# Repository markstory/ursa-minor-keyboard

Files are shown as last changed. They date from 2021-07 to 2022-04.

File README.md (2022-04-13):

# Ursa Minor Keyboard

This repository contains design and schematic files for the usra-minor keyboard design.

## Handwired

This directory contains the design files used to create the initial prototype of the tryptris keyboard.
You can find a design/build guide on my blog:

* [Part 1](http://mark-story.com/posts/view/building-a-split-keyboard-part-1)
* [Part 2](http://mark-story.com/posts/view/building-a-split-keyboard-part-2)
* [Part 3](http://mark-story.com/posts/view/building-a-split-keyboard-part-3)

## v01

This directory contains the first drafts of the PCB based build. I've completed
design on two variants. Both have been printed and tested. A few defects were
found in the `v01/bling` board. These defects have been corrected. I've posted
a [longer article on the design and production](http://mark-story.com/posts/view/designing-my-first-keyboard-pcb).

### Notable Features

* **Single MCU** - Instead of dual microcontrollers, this design uses only
  a microcontroller and IO expander pairing. This lets more cost effective
  components be used and only requires a single flash operation when updating
  firmware.
* **Thumb Arc** The thumb cluster follows the thumb's natural arc, and all keys
  are reachable in 1u of space. Unlike many thumb arcs, this one requires no
  reaching under the palm.
* **No Frills, or Frills** The base model has a simple stripped down keyboard.
  It has no lights, no encoders, just 58 switches and wires. The bling model
  includes support for per-key RGB.

### v01/base

**🖨Printed, ✅Tested**

This is a basic board design. It has has no frills and a smaller parts list. The intention is that it used caseless with self-adhesive feet, or directly on a desk.

### v01/bling

**🖨Printed, ✅Tested**

This design builds on caseless foundatin of the `v01/base` and adds per-key RGB lighting via RGB matrix drivers over I2C. Like the base board it is intended to be used caseless.

### v01/bling-case

**🏗Work In Progress**

This board is a distinct design from `v01/bling` & `v01/base`. It is intended to be used with a switch plate and hollow body case.

### Firmware

Firmware for the `v01/base` and `v01/bling` can be found [in my QMK fork][https://github.com/markstory/qmk_firmare/tree/ursa-minor-v1].

## FAQ

**Why Ursa Minor?**

The keypad shape and thumb arc remind me of [Ursa Minor](https://en.wikipedia.org/wiki/Ursa_Minor).

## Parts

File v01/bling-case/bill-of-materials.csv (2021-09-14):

Id | Designator | Package | Quantity | Designation | Supplier | Part number | Price per | Total per board
3 | C16,C19,C18,C17,C15,C14,C6,C5,C4 | C_0805_2012Metric | 9 | 0.1uF | digikey | 08053C104KAT2A | 0.14 | 1.26
4 | U4,U3 | TQFP-48-1EP_7x7mm_P0.5mm_EP5x5mm | 2 | IS31FL3733-TQ | digikey | IS31FL3733B-TQLS4-TR | 4.94 | 9.88
5 | R14,R13 | R_0805_2012Metric | 2 | 20K | digikey | RMCF0805JT20K0 | 0.15 | 0.3
6 | R12,R11,R10,R9 | R_0805_2012Metric | 4 | 100K | digikey | RMCF0805JT100K | 0.15 | 0.6
7 | D1-54 | RGB_3528_Blue_Notch-MX | 54 | 6028 LED | aliexpress | /item/32834931333 | 0.122142857142857 | 6.59571428571429
8 | C21,C20,C13,C12,C11,C10,C9,C8 | C_0805_2012Metric | 8 | 0.47uF | digikey | CL21B474KOFNNNE | 0.14 | 1.12
10 | R7,R6 | R_0805_2012Metric | 2 | 4.7k | digikey | ERJ-PB6B4701V | 0.48 | 0.96
11 | J3 | USB_C_GCT_USB4085 | 1 | I2C-R | mouser | USB4085-GF-A | 1.28 | 1.28
12 | J2 | USB_C_GCT_USB4085 | 1 | I2C-L | mouser | USB4085-GF-A | 1.28 | 1.28
73 | J1 | USB_C_GCT_USB4085 | 1 | USB_C_Receptacle_USB2.0 | mouser | USB4085-GF-A | 1.28 | 1.28
16 | F1 | Fuse_0805_2012Metric_Pad1.15x1.40mm_HandSolder | 1 | 500mA | digikey | 0ZCK0050FF2E | 0.25 | 0.25
17 | D1-54 | D_SOD-123 | 54 | 1N4148W | digikey | 1N4148W RHG | 0.23 | 12.42
20 | SW1 | SW_SPST_TL3342 | 1 | Reset | digikey | TL3342F160QG/TR | 0.96 | 0.96
74 | Y1 | Crystal_SMD_3225-4Pin_3.2x2.5mm | 1 | 16Mhz | digikey | ECS-160-8-33-RHN-TR | 0.81 | 0.81
75 | U2 | SOIC-28W_7.5x17.9mm_P1.27mm | 1 | MCP23017_SO | mouser | 579-MCP23017T-E/SO | 1.92 | 1.92
76 | U1 | TQFP-44_10x10mm_P0.8mm | 1 | ATmega32U4-AU | digikey | ATMEGA32U4RC-AU | 7.46 | 7.46
77 | R8,R1 | R_0805_2012Metric | 2 | 10k | digikey | RMCF0805JT10K0 | 0.15 | 0.3
78 | R5,R4 | R_0805_2012Metric | 2 | 22 | digikey | RMCF0805FT22R0 | 0.15 | 0.3
79 | R3,R2 | R_0805_2012Metric | 2 | 5.1K | digikey | RMCF0805FT5K10 | 0.15 | 0.3
80 | C7 | C_0805_2012Metric | 1 | 10uF | digikey | C0805C106K9PACTU | 0.2 | 0.2
81 | C3 | C_0805_2012Metric | 1 | 1uF | digikey | 08056D104KAT2A | 0.14 | 0.14
82 | C2,C1 | C_0805_2012Metric | 2 | 22pF | digikey | CL21A226MQQNNNE | 0.2 | 0.4
 |  |  |  |  |  |  |  | 50.0157142857143

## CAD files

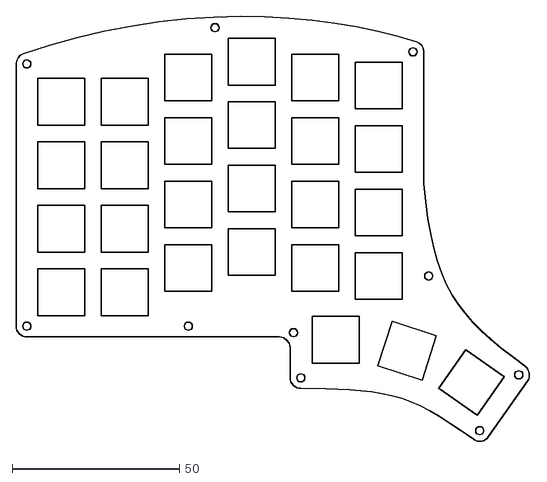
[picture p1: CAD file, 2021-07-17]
handwired/switchplate.dxf
154.1 x 127.3

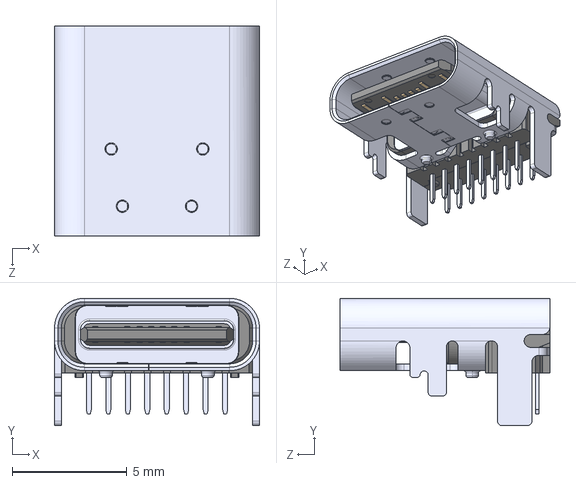
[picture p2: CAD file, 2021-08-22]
sym/3dmodels/USB4085-GF-A.step
8.95 x 5.56 x 9.17 mm

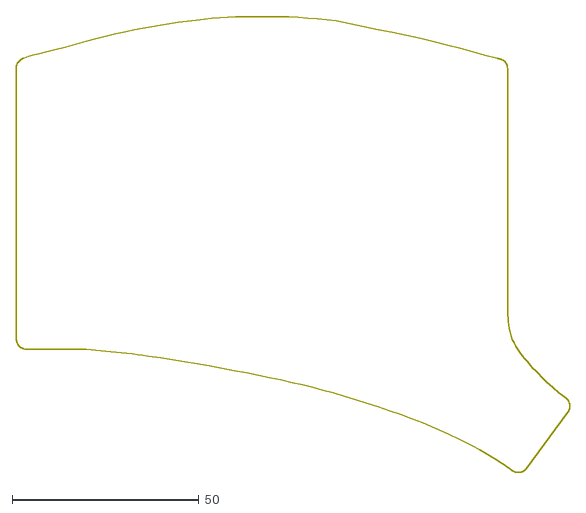
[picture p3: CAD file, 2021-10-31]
v01/drawing/left-board-outline.dxf
148.1 x 122.0

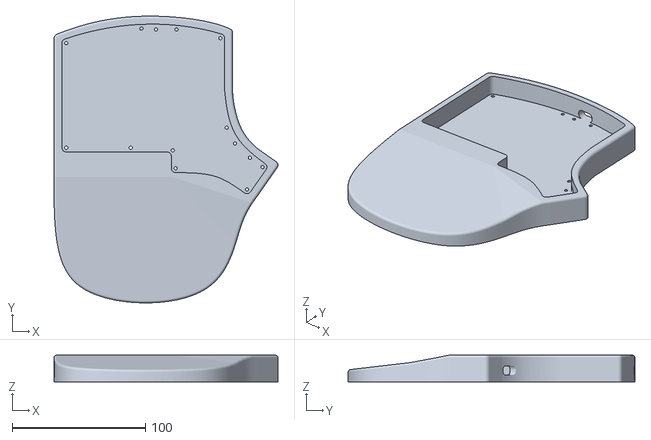
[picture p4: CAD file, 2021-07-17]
handwired/case-palmrest.stl
168.0 x 215.1 x 20.0

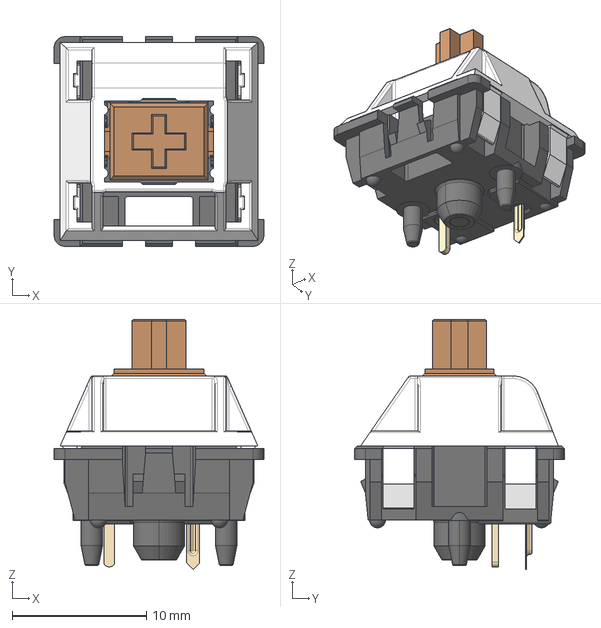
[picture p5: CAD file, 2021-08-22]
sym/3dmodels/MX-Alps-Choc-1U-NoLED.step
15.6 x 15.6 x 18.6 mm

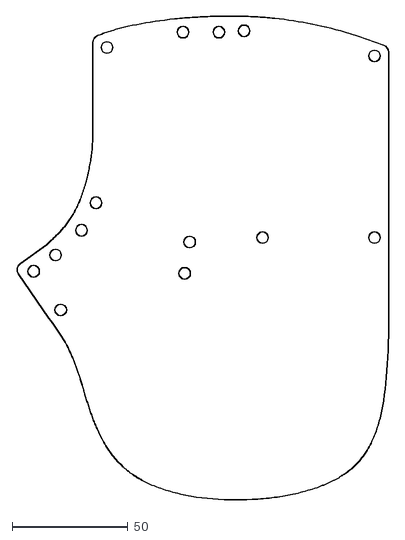
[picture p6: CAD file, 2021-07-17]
handwired/palmrest-mat.dxf
161.0 x 209.1

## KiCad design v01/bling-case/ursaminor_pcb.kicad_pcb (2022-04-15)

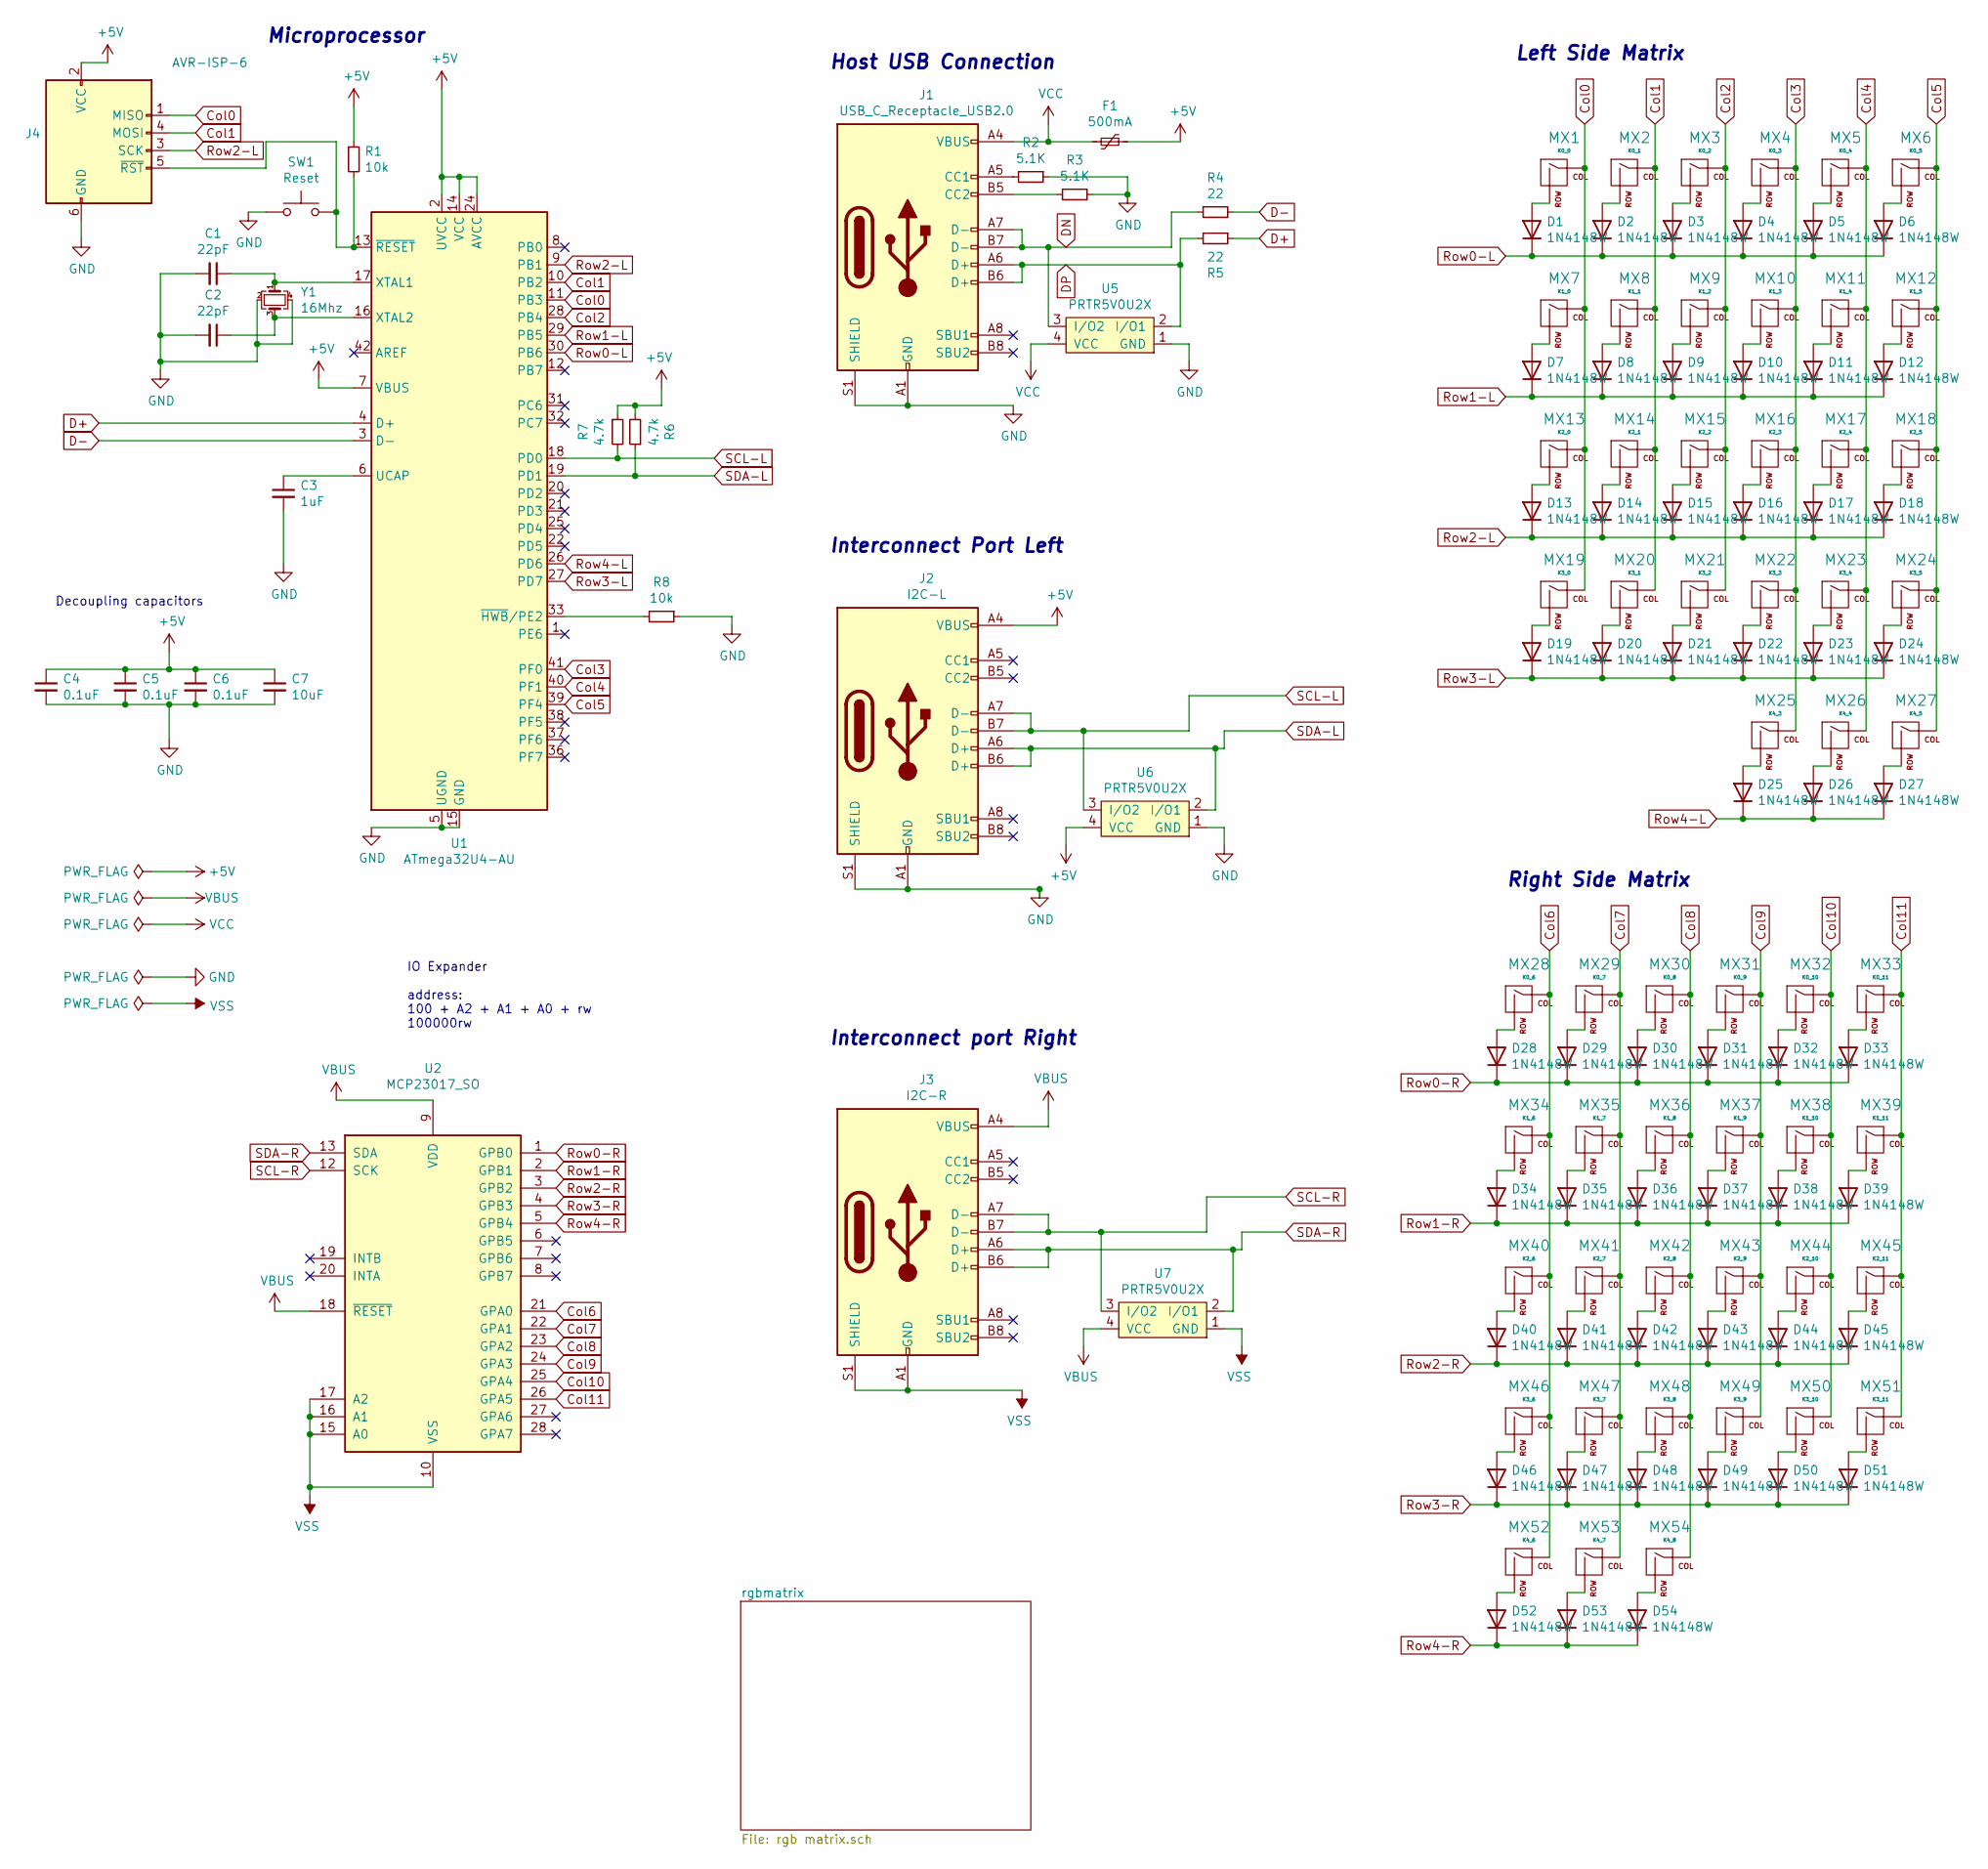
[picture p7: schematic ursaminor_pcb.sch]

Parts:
C1, C2: 22pF; C_0805_2012Metric
C3: 1uF; C_0805_2012Metric
C4, C5, C6: 0.1uF; C_0805_2012Metric
C7: 10uF; C_0805_2012Metric
D1, D2, D3, D4, D5, D6, D7, D8, D9, D10, D11, D12, D13, D14, D15, D16, D17, D18, D19, D20, D21, D22, D23, D24, D25, D26, D27, D28, D29, D30, D31, D32, D33, D34, D35, D36, D37, D38, D39, D40, D41, D42, D43, D44, D45, D46, D47, D48, D49, D50, D51, D52, D53, D54: 1N4148W; D_SOD-123
F1: 500mA; Fuse_1206_3216Metric_Pad1.42x1.75mm_HandSolder
J1: USB_C_Receptacle_USB2.0; USB_C_Receptacle_HRO_TYPE-C-31-M-12
J2: I2C-L; USB_C_Receptacle_HRO_TYPE-C-31-M-12
J3: I2C-R; USB_C_Receptacle_HRO_TYPE-C-31-M-12
J4: AVR-ISP-6; Reset_Pretty-Mask
MX1: K0_0; MX-Alps-Choc-1U-NoLED
MX2: K0_1; MX-Alps-Choc-1U-NoLED
MX3: K0_2; MX-Alps-Choc-1U-NoLED
MX4: K0_3; MX-Alps-Choc-1U-NoLED
MX5: K0_4; MX-Alps-Choc-1U-NoLED
MX6: K0_5; MX-Alps-Choc-1U-NoLED
MX7: K1_0; MX-Alps-Choc-1U-NoLED
MX8: K1_1; MX-Alps-Choc-1U-NoLED
MX9: K1_2; MX-Alps-Choc-1U-NoLED
MX10: K1_3; MX-Alps-Choc-1U-NoLED
MX11: K1_4; MX-Alps-Choc-1U-NoLED
MX12: K1_5; MX-Alps-Choc-1U-NoLED
MX13: K2_0; MX-Alps-Choc-1U-NoLED
MX14: K2_1; MX-Alps-Choc-1U-NoLED
MX15: K2_2; MX-Alps-Choc-1U-NoLED
MX16: K2_3; MX-Alps-Choc-1U-NoLED
MX17: K2_4; MX-Alps-Choc-1U-NoLED
MX18: K2_5; MX-Alps-Choc-1U-NoLED
MX19: K3_0; MX-Alps-Choc-1U-NoLED
MX20: K3_1; MX-Alps-Choc-1U-NoLED
MX21: K3_2; MX-Alps-Choc-1U-NoLED
MX22: K3_3; MX-Alps-Choc-1U-NoLED
MX23: K3_4; MX-Alps-Choc-1U-NoLED
MX24: K3_5; MX-Alps-Choc-1U-NoLED
MX25: K4_3; MX-Alps-Choc-1U-NoLED
MX26: K4_4; MX-Alps-Choc-1U-NoLED
MX27: K4_5; MX-Alps-Choc-1U-NoLED
MX28: K0_6; MX-Alps-Choc-1U-NoLED
MX29: K0_7; MX-Alps-Choc-1U-NoLED
MX30: K0_8; MX-Alps-Choc-1U-NoLED
MX31: K0_9; MX-Alps-Choc-1U-NoLED
MX32: K0_10; MX-Alps-Choc-1U-NoLED
MX33: K0_11; MX-Alps-Choc-1U-NoLED
MX34: K1_6; MX-Alps-Choc-1U-NoLED
MX35: K1_7; MX-Alps-Choc-1U-NoLED
MX36: K1_8; MX-Alps-Choc-1U-NoLED
MX37: K1_9; MX-Alps-Choc-1U-NoLED
MX38: K1_10; MX-Alps-Choc-1U-NoLED
MX39: K1_11; MX-Alps-Choc-1U-NoLED
MX40: K2_6; MX-Alps-Choc-1U-NoLED
MX41: K2_7; MX-Alps-Choc-1U-NoLED
MX42: K2_8; MX-Alps-Choc-1U-NoLED
MX43: K2_9; MX-Alps-Choc-1U-NoLED
MX44: K2_10; MX-Alps-Choc-1U-NoLED
MX45: K2_11; MX-Alps-Choc-1U-NoLED
MX46: K3_6; MX-Alps-Choc-1U-NoLED
MX47: K3_7; MX-Alps-Choc-1U-NoLED
MX48: K3_8; MX-Alps-Choc-1U-NoLED
MX49: K3_9; MX-Alps-Choc-1U-NoLED
MX50: K3_10; MX-Alps-Choc-1U-NoLED
MX51: K3_11; MX-Alps-Choc-1U-NoLED
MX52: K4_6; MX-Alps-Choc-1U-NoLED
MX53: K4_7; MX-Alps-Choc-1U-NoLED
MX54: K4_8; MX-Alps-Choc-1U-NoLED
R1, R8: 10k; R_0805_2012Metric
R2, R3: 5.1K; R_0805_2012Metric
R4, R5: 22; R_0805_2012Metric
R6, R7: 4.7k; R_0805_2012Metric
SW1: Reset; SW_SPST_TL3342
U1: ATmega32U4-AU; TQFP-44_10x10mm_P0.8mm
U2: MCP23017_SO; SOIC-28W_7.5x17.9mm_P1.27mm
U5, U6, U7: PRTR5V0U2X; SOT-143B
Y1: 16Mhz; Crystal_SMD_3225-4Pin_3.2x2.5mm

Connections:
+5V: C4.1, C5.1, C6.1, C7.1, F1.1, J2.A4 (VBUS), J2.A9 (VBUS), J2.B4 (VBUS), J2.B9 (VBUS), J4.2 (VCC), R1.1, R6.2, R7.1, U1.2 (UVCC), U1.7 (VBUS), U1.14 (VCC), U1.24 (AVCC), U1.34 (VCC), U1.44 (AVCC), U6.4 (VCC); also elsewhere on the board
Col0: J4.1 (MISO), MX1.1 (COL), MX7.1 (COL), MX13.1 (COL), MX19.1 (COL), U1.11 (PB3)
Col1: J4.4 (MOSI), MX2.1 (COL), MX8.1 (COL), MX14.1 (COL), MX20.1 (COL), U1.10 (PB2)
Col2: MX3.1 (COL), MX9.1 (COL), MX15.1 (COL), MX21.1 (COL), U1.28 (PB4)
Col3: MX4.1 (COL), MX10.1 (COL), MX16.1 (COL), MX22.1 (COL), MX25.1 (COL), U1.41 (PF0)
Col4: MX5.1 (COL), MX11.1 (COL), MX17.1 (COL), MX23.1 (COL), MX26.1 (COL), U1.40 (PF1)
Col5: MX6.1 (COL), MX12.1 (COL), MX18.1 (COL), MX24.1 (COL), MX27.1 (COL), U1.39 (PF4)
Col6: MX28.1 (COL), MX34.1 (COL), MX40.1 (COL), MX46.1 (COL), MX52.1 (COL), U2.21 (GPA0)
Col7: MX29.1 (COL), MX35.1 (COL), MX41.1 (COL), MX47.1 (COL), MX53.1 (COL), U2.22 (GPA1)
Col8: MX30.1 (COL), MX36.1 (COL), MX42.1 (COL), MX48.1 (COL), MX54.1 (COL), U2.23 (GPA2)
Col9: MX31.1 (COL), MX37.1 (COL), MX43.1 (COL), MX49.1 (COL), U2.24 (GPA3)
Col10: MX32.1 (COL), MX38.1 (COL), MX44.1 (COL), MX50.1 (COL), U2.25 (GPA4)
Col11: MX33.1 (COL), MX39.1 (COL), MX45.1 (COL), MX51.1 (COL), U2.26 (GPA5)
D+: R5.1, U1.4 (D+)
D-: R4.2, U1.3 (D-)
DN: J1.A7 (D-), J1.B7 (D-), R4.1, U5.3 (I/O2)
DP: J1.A6 (D+), J1.B6 (D+), R5.2, U5.2 (I/O1)
GND: C1.2, C2.2, C3.2, C4.2, C5.2, C6.2, C7.2, J1.A1 (GND), J1.A12 (GND), J1.B1 (GND), J1.B12 (GND), J1.S1 (SHIELD), J2.A1 (GND), J2.A12 (GND), J2.B1 (GND), J2.B12 (GND), J2.S1 (SHIELD), J4.6 (GND), R2.1, R3.2, R8.1, SW1.1, U1.5 (UGND), U1.15 (GND), U1.23 (GND), U1.35 (GND), U1.43 (GND), U5.1 (GND), U6.1 (GND), Y1.2, Y1.4; also elsewhere on the board
unnamed: C1.1, U1.17 (XTAL1), Y1.1
unnamed: C2.1, U1.16 (XTAL2), Y1.3
unnamed: C3.1, U1.6 (UCAP)
unnamed: D1.2 (A), MX1.2 (ROW)
unnamed: D2.2 (A), MX2.2 (ROW)
unnamed: D3.2 (A), MX3.2 (ROW)
unnamed: D4.2 (A), MX4.2 (ROW)
unnamed: D5.2 (A), MX5.2 (ROW)
unnamed: D6.2 (A), MX6.2 (ROW)
unnamed: D7.2 (A), MX7.2 (ROW)
unnamed: D8.2 (A), MX8.2 (ROW)
unnamed: D9.2 (A), MX9.2 (ROW)
unnamed: D10.2 (A), MX10.2 (ROW)
unnamed: D11.2 (A), MX11.2 (ROW)
unnamed: D12.2 (A), MX12.2 (ROW)
unnamed: D13.2 (A), MX13.2 (ROW)
unnamed: D14.2 (A), MX14.2 (ROW)
unnamed: D15.2 (A), MX15.2 (ROW)
unnamed: D16.2 (A), MX16.2 (ROW)
unnamed: D17.2 (A), MX17.2 (ROW)
unnamed: D18.2 (A), MX18.2 (ROW)
unnamed: D19.2 (A), MX19.2 (ROW)
unnamed: D20.2 (A), MX20.2 (ROW)
unnamed: D21.2 (A), MX21.2 (ROW)
unnamed: D22.2 (A), MX22.2 (ROW)
unnamed: D23.2 (A), MX23.2 (ROW)
unnamed: D24.2 (A), MX24.2 (ROW)
unnamed: D25.2 (A), MX25.2 (ROW)
unnamed: D26.2 (A), MX26.2 (ROW)
unnamed: D27.2 (A), MX27.2 (ROW)
unnamed: D28.2 (A), MX28.2 (ROW)
unnamed: D29.2 (A), MX29.2 (ROW)
unnamed: D30.2 (A), MX30.2 (ROW)
unnamed: D31.2 (A), MX31.2 (ROW)
unnamed: D32.2 (A), MX32.2 (ROW)
unnamed: D33.2 (A), MX33.2 (ROW)
unnamed: D34.2 (A), MX34.2 (ROW)
unnamed: D35.2 (A), MX35.2 (ROW)
unnamed: D36.2 (A), MX36.2 (ROW)
unnamed: D37.2 (A), MX37.2 (ROW)
unnamed: D38.2 (A), MX38.2 (ROW)
unnamed: D39.2 (A), MX39.2 (ROW)
unnamed: D40.2 (A), MX40.2 (ROW)
unnamed: D41.2 (A), MX41.2 (ROW)
unnamed: D42.2 (A), MX42.2 (ROW)
unnamed: D43.2 (A), MX43.2 (ROW)
unnamed: D44.2 (A), MX44.2 (ROW)
unnamed: D45.2 (A), MX45.2 (ROW)
unnamed: D46.2 (A), MX46.2 (ROW)
unnamed: D47.2 (A), MX47.2 (ROW)
unnamed: D48.2 (A), MX48.2 (ROW)
unnamed: D49.2 (A), MX49.2 (ROW)
unnamed: D50.2 (A), MX50.2 (ROW)
unnamed: D51.2 (A), MX51.2 (ROW)
unnamed: D52.2 (A), MX52.2 (ROW)
unnamed: D53.2 (A), MX53.2 (ROW)
unnamed: D54.2 (A), MX54.2 (ROW)
unnamed: J1.A5 (CC1), R2.2
unnamed: J1.B5 (CC2), R3.1
unnamed: J4.5 (~RST), R1.2, SW1.2, U1.13 (~RESET)
unnamed: R8.2, U1.33 (~HWB~/PE2)
Row0-L: D1.1 (K), D2.1 (K), D3.1 (K), D4.1 (K), D5.1 (K), D6.1 (K), U1.30 (PB6)
Row0-R: D28.1 (K), D29.1 (K), D30.1 (K), D31.1 (K), D32.1 (K), D33.1 (K), U2.1 (GPB0)
Row1-L: D7.1 (K), D8.1 (K), D9.1 (K), D10.1 (K), D11.1 (K), D12.1 (K), U1.29 (PB5)
Row1-R: D34.1 (K), D35.1 (K), D36.1 (K), D37.1 (K), D38.1 (K), D39.1 (K), U2.2 (GPB1)
Row2-L: D13.1 (K), D14.1 (K), D15.1 (K), D16.1 (K), D17.1 (K), D18.1 (K), J4.3 (SCK), U1.9 (PB1)
Row2-R: D40.1 (K), D41.1 (K), D42.1 (K), D43.1 (K), D44.1 (K), D45.1 (K), U2.3 (GPB2)
Row3-L: D19.1 (K), D20.1 (K), D21.1 (K), D22.1 (K), D23.1 (K), D24.1 (K), U1.27 (PD7)
Row3-R: D46.1 (K), D47.1 (K), D48.1 (K), D49.1 (K), D50.1 (K), D51.1 (K), U2.4 (GPB3)
Row4-L: D25.1 (K), D26.1 (K), D27.1 (K), U1.26 (PD6)
Row4-R: D52.1 (K), D53.1 (K), D54.1 (K), U2.5 (GPB4)
SCL-L: J2.A7 (D-), J2.B7 (D-), R7.2, U1.18 (PD0), U6.3 (I/O2); also elsewhere on the board
SCL-R: J3.A7 (D-), J3.B7 (D-), U2.12 (SCK), U7.3 (I/O2); also elsewhere on the board
SDA-L: J2.A6 (D+), J2.B6 (D+), R6.1, U1.19 (PD1), U6.2 (I/O1); also elsewhere on the board
SDA-R: J3.A6 (D+), J3.B6 (D+), U2.13 (SDA), U7.2 (I/O1); also elsewhere on the board
VBUS: J3.A4 (VBUS), J3.A9 (VBUS), J3.B4 (VBUS), J3.B9 (VBUS), U2.9 (VDD), U2.18 (~RESET~), U7.4 (VCC); also elsewhere on the board
VCC: F1.2, J1.A4 (VBUS), J1.A9 (VBUS), J1.B4 (VBUS), J1.B9 (VBUS), U5.4 (VCC)
VSS: J3.A1 (GND), J3.A12 (GND), J3.B1 (GND), J3.B12 (GND), J3.S1 (SHIELD), U2.10 (VSS), U2.15 (A0), U2.16 (A1), U2.17 (A2), U7.1 (GND); also elsewhere on the board

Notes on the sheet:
Left Side Matrix
Host USB Connection
Microprocessor
Decoupling capacitors
IO Expander address: 100 + A2 + A1 + A0 + rw 100000rw
Right Side Matrix
Interconnect port Right
Interconnect Port Left

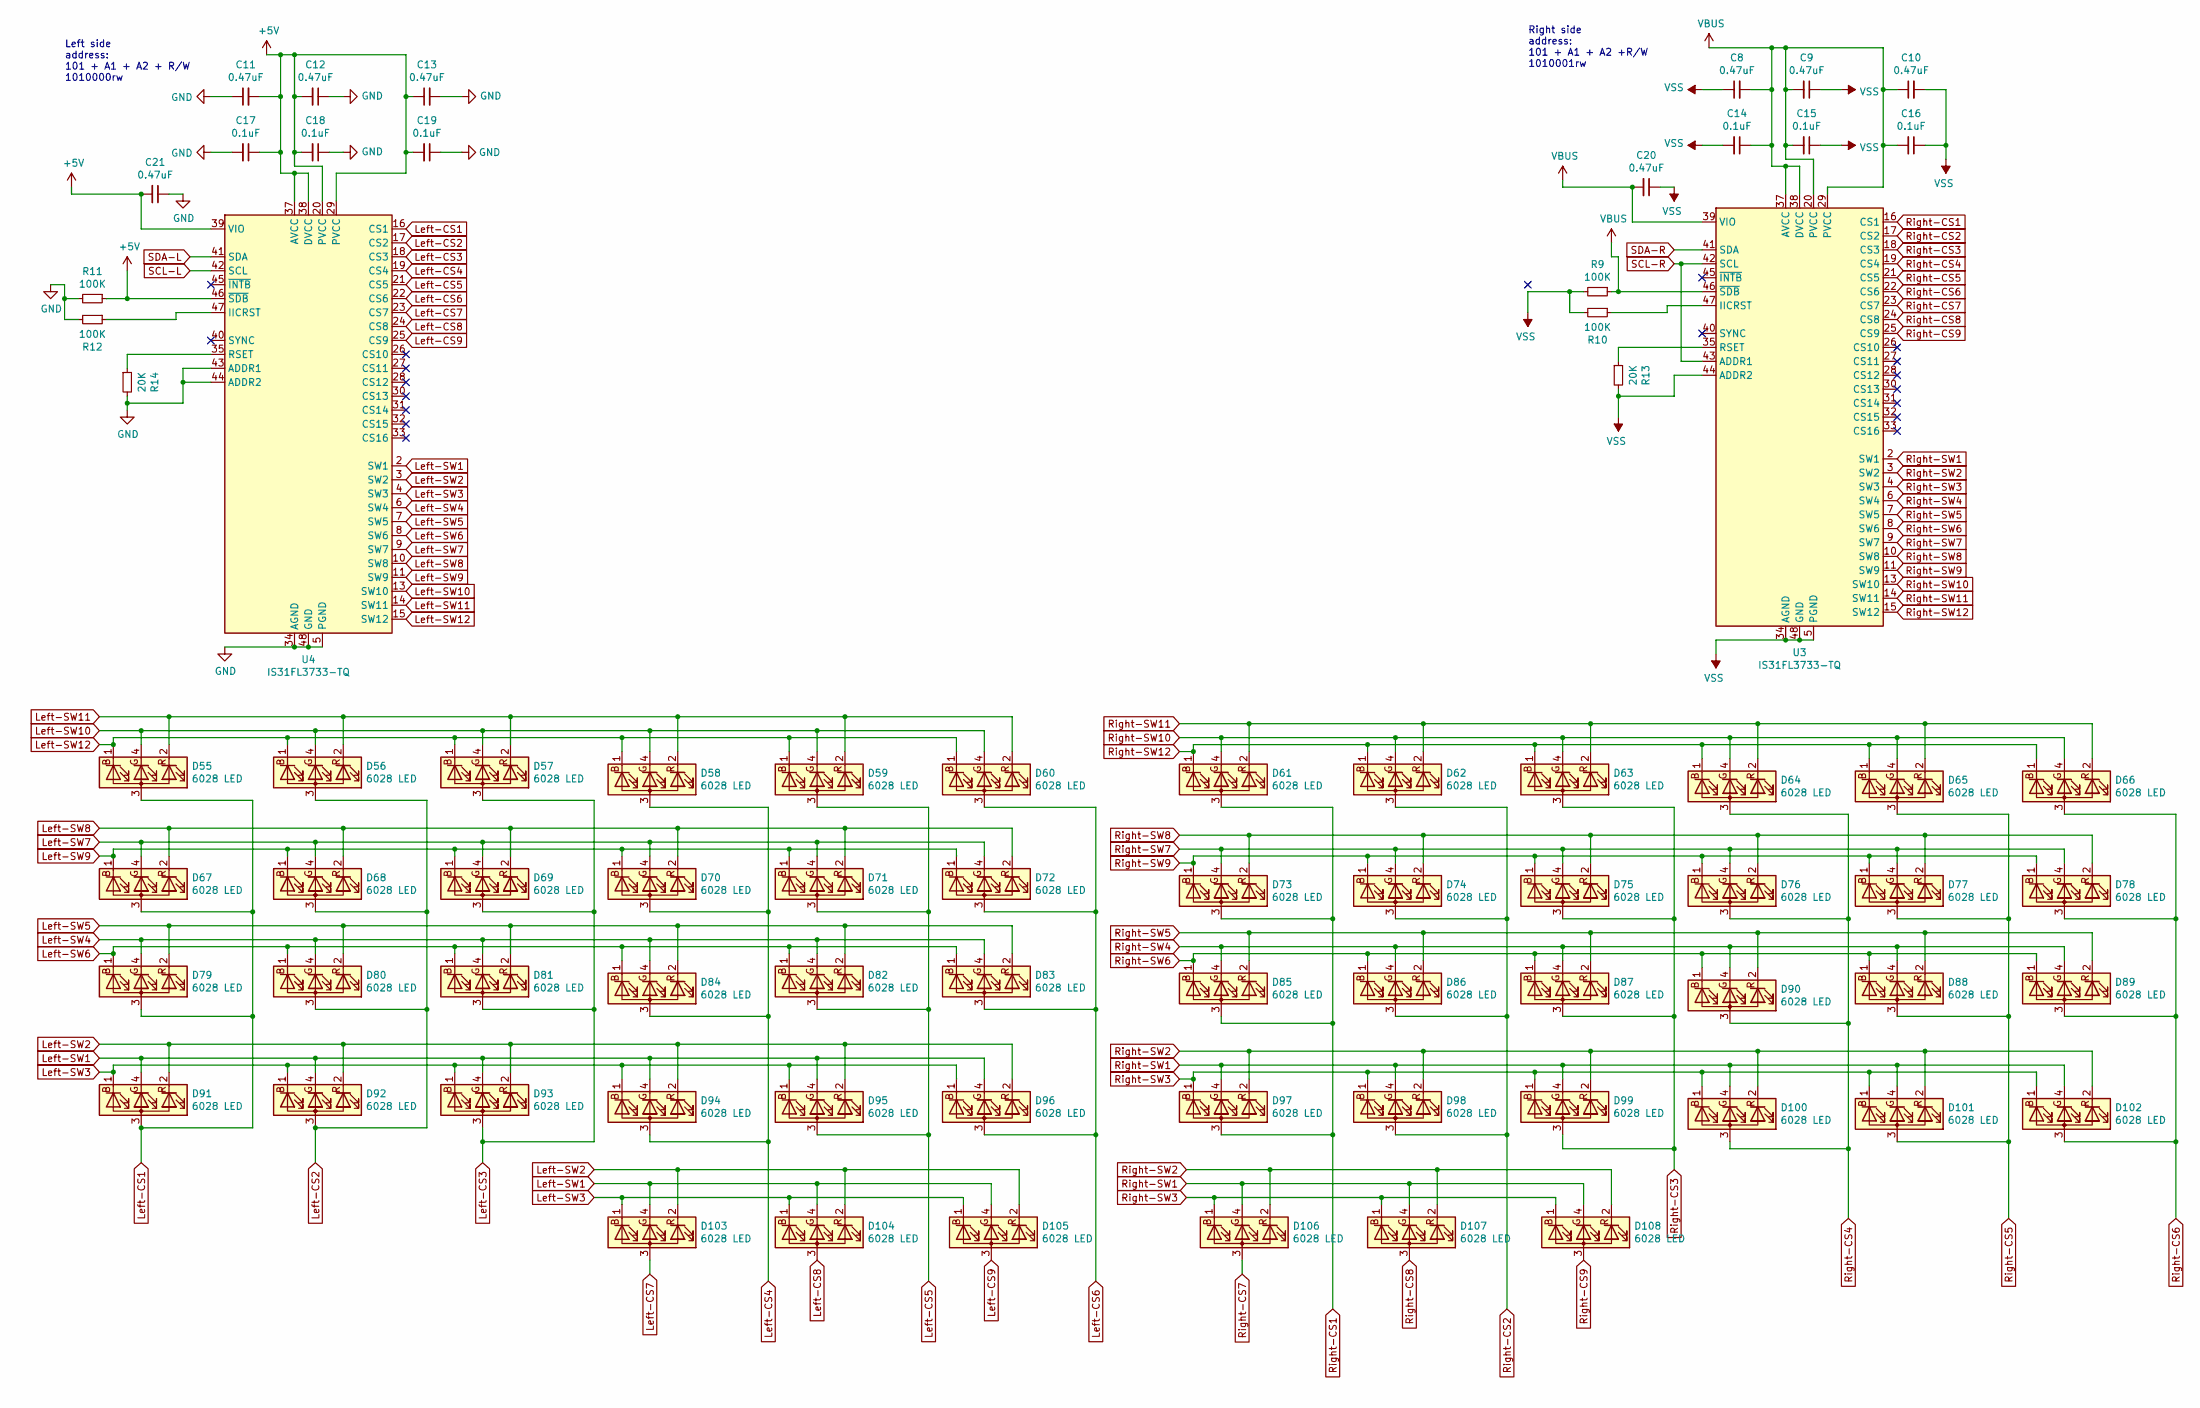
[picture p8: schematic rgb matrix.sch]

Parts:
C8, C9, C10, C11, C12, C13, C20, C21: 0.47uF; C_0805_2012Metric
C14, C15, C16, C17, C18, C19: 0.1uF; C_0805_2012Metric
D55, D56, D57, D58, D59, D60, D61, D62, D63, D64, D65, D66, D67, D68, D69, D70, D71, D72, D73, D74, D75, D76, D77, D78, D79, D80, D81, D82, D83, D84, D85, D86, D87, D88, D89, D90, D91, D92, D93, D94, D95, D96, D97, D98, D99, D100, D101, D102, D103, D104, D105, D106, D107, D108: 6028 LED; RGB_3528_Blue_Notch-MX
R9, R10, R11, R12: 100K; R_0805_2012Metric
R13, R14: 20K; R_0805_2012Metric
U3, U4: IS31FL3733-TQ; TQFP-48-1EP_7x7mm_P0.5mm_EP5x5mm

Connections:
+5V: C11.2, C12.2, C13.1, C17.1, C18.2, C19.2, C21.2, R11.1, U4.20 (PVCC), U4.29 (PVCC), U4.37 (AVCC), U4.38 (DVCC), U4.39 (VIO), U4.46 (~SDB); also elsewhere on the board
GND: C11.1, C12.1, C13.2, C17.2, C18.1, C19.1, C21.1, R11.2, R12.2, R14.2, U4.5 (PGND), U4.12 (PGND), U4.34 (AGND), U4.43 (ADDR1), U4.44 (ADDR2), U4.48 (GND), U4.49 (GND); also elsewhere on the board
Left-CS1: D55.3 (A), D67.3 (A), D79.3 (A), D91.3 (A), U4.16 (CS1)
Left-CS2: D56.3 (A), D68.3 (A), D80.3 (A), D92.3 (A), U4.17 (CS2)
Left-CS3: D57.3 (A), D69.3 (A), D81.3 (A), D93.3 (A), U4.18 (CS3)
Left-CS4: D58.3 (A), D70.3 (A), D84.3 (A), D94.3 (A), U4.19 (CS4)
Left-CS5: D59.3 (A), D71.3 (A), D82.3 (A), D95.3 (A), U4.21 (CS5)
Left-CS6: D60.3 (A), D72.3 (A), D83.3 (A), D96.3 (A), U4.22 (CS6)
Left-CS7: D103.3 (A), U4.23 (CS7)
Left-CS8: D104.3 (A), U4.24 (CS8)
Left-CS9: D105.3 (A), U4.25 (CS9)
Left-SW1: D91.4 (GK), D92.4 (GK), D93.4 (GK), D94.4 (GK), D95.4 (GK), D96.4 (GK), D103.4 (GK), D104.4 (GK), D105.4 (GK), U4.2 (SW1)
Left-SW2: D91.2 (RK), D92.2 (RK), D93.2 (RK), D94.2 (RK), D95.2 (RK), D96.2 (RK), D103.2 (RK), D104.2 (RK), D105.2 (RK), U4.3 (SW2)
Left-SW3: D91.1 (BK), D92.1 (BK), D93.1 (BK), D94.1 (BK), D95.1 (BK), D96.1 (BK), D103.1 (BK), D104.1 (BK), D105.1 (BK), U4.4 (SW3)
Left-SW4: D79.4 (GK), D80.4 (GK), D81.4 (GK), D82.4 (GK), D83.4 (GK), D84.4 (GK), U4.6 (SW4)
Left-SW5: D79.2 (RK), D80.2 (RK), D81.2 (RK), D82.2 (RK), D83.2 (RK), D84.2 (RK), U4.7 (SW5)
Left-SW6: D79.1 (BK), D80.1 (BK), D81.1 (BK), D82.1 (BK), D83.1 (BK), D84.1 (BK), U4.8 (SW6)
Left-SW7: D67.4 (GK), D68.4 (GK), D69.4 (GK), D70.4 (GK), D71.4 (GK), D72.4 (GK), U4.9 (SW7)
Left-SW8: D67.2 (RK), D68.2 (RK), D69.2 (RK), D70.2 (RK), D71.2 (RK), D72.2 (RK), U4.10 (SW8)
Left-SW9: D67.1 (BK), D68.1 (BK), D69.1 (BK), D70.1 (BK), D71.1 (BK), D72.1 (BK), U4.11 (SW9)
Left-SW10: D55.4 (GK), D56.4 (GK), D57.4 (GK), D58.4 (GK), D59.4 (GK), D60.4 (GK), U4.13 (SW10)
Left-SW11: D55.2 (RK), D56.2 (RK), D57.2 (RK), D58.2 (RK), D59.2 (RK), D60.2 (RK), U4.14 (SW11)
Left-SW12: D55.1 (BK), D56.1 (BK), D57.1 (BK), D58.1 (BK), D59.1 (BK), D60.1 (BK), U4.15 (SW12)
unnamed: R10.1, U3.47 (IICRST)
unnamed: R12.1, U4.47 (IICRST)
unnamed: R13.1, U3.35 (RSET)
unnamed: R14.1, U4.35 (RSET)
Right-CS1: D61.3 (A), D73.3 (A), D85.3 (A), D97.3 (A), U3.16 (CS1)
Right-CS2: D62.3 (A), D74.3 (A), D86.3 (A), D98.3 (A), U3.17 (CS2)
Right-CS3: D63.3 (A), D75.3 (A), D87.3 (A), D99.3 (A), U3.18 (CS3)
Right-CS4: D64.3 (A), D76.3 (A), D90.3 (A), D100.3 (A), U3.19 (CS4)
Right-CS5: D65.3 (A), D77.3 (A), D88.3 (A), D101.3 (A), U3.21 (CS5)
Right-CS6: D66.3 (A), D78.3 (A), D89.3 (A), D102.3 (A), U3.22 (CS6)
Right-CS7: D106.3 (A), U3.23 (CS7)
Right-CS8: D107.3 (A), U3.24 (CS8)
Right-CS9: D108.3 (A), U3.25 (CS9)
Right-SW1: D97.4 (GK), D98.4 (GK), D99.4 (GK), D100.4 (GK), D101.4 (GK), D102.4 (GK), D106.4 (GK), D107.4 (GK), D108.4 (GK), U3.2 (SW1)
Right-SW2: D97.2 (RK), D98.2 (RK), D99.2 (RK), D100.2 (RK), D101.2 (RK), D102.2 (RK), D106.2 (RK), D107.2 (RK), D108.2 (RK), U3.3 (SW2)
Right-SW3: D97.1 (BK), D98.1 (BK), D99.1 (BK), D100.1 (BK), D101.1 (BK), D102.1 (BK), D106.1 (BK), D107.1 (BK), D108.1 (BK), U3.4 (SW3)
Right-SW4: D85.4 (GK), D86.4 (GK), D87.4 (GK), D88.4 (GK), D89.4 (GK), D90.4 (GK), U3.6 (SW4)
Right-SW5: D85.2 (RK), D86.2 (RK), D87.2 (RK), D88.2 (RK), D89.2 (RK), D90.2 (RK), U3.7 (SW5)
Right-SW6: D85.1 (BK), D86.1 (BK), D87.1 (BK), D88.1 (BK), D89.1 (BK), D90.1 (BK), U3.8 (SW6)
Right-SW7: D73.4 (GK), D74.4 (GK), D75.4 (GK), D76.4 (GK), D77.4 (GK), D78.4 (GK), U3.9 (SW7)
Right-SW8: D73.2 (RK), D74.2 (RK), D75.2 (RK), D76.2 (RK), D77.2 (RK), D78.2 (RK), U3.10 (SW8)
Right-SW9: D73.1 (BK), D74.1 (BK), D75.1 (BK), D76.1 (BK), D77.1 (BK), D78.1 (BK), U3.11 (SW9)
Right-SW10: D61.4 (GK), D62.4 (GK), D63.4 (GK), D64.4 (GK), D65.4 (GK), D66.4 (GK), U3.13 (SW10)
Right-SW11: D61.2 (RK), D62.2 (RK), D63.2 (RK), D64.2 (RK), D65.2 (RK), D66.2 (RK), U3.14 (SW11)
Right-SW12: D61.1 (BK), D62.1 (BK), D63.1 (BK), D64.1 (BK), D65.1 (BK), D66.1 (BK), U3.15 (SW12)
SCL-L: U4.42 (SCL); also elsewhere on the board
SCL-R: U3.42 (SCL), U3.43 (ADDR1); also elsewhere on the board
SDA-L: U4.41 (SDA); also elsewhere on the board
SDA-R: U3.41 (SDA); also elsewhere on the board
VBUS: C8.2, C9.2, C10.1, C14.1, C15.2, C16.2, C20.2, R9.1, U3.20 (PVCC), U3.29 (PVCC), U3.37 (AVCC), U3.38 (DVCC), U3.39 (VIO), U3.46 (~SDB); also elsewhere on the board
VSS: C8.1, C9.1, C10.2, C14.2, C15.1, C16.1, C20.1, R9.2, R10.2, R13.2, U3.5 (PGND), U3.12 (PGND), U3.34 (AGND), U3.44 (ADDR2), U3.48 (GND), U3.49 (GND); also elsewhere on the board

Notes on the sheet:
Left side address: 101 + A1 + A2 + R/W 1010000rw
Right side address: 101 + A1 + A2 +R/W 1010001rw

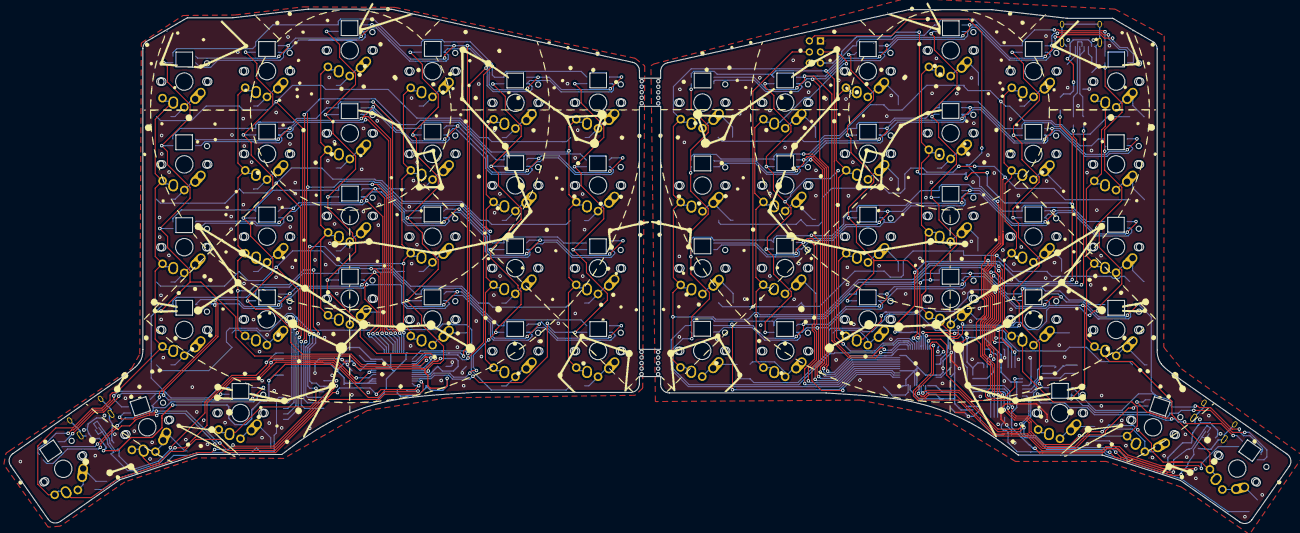
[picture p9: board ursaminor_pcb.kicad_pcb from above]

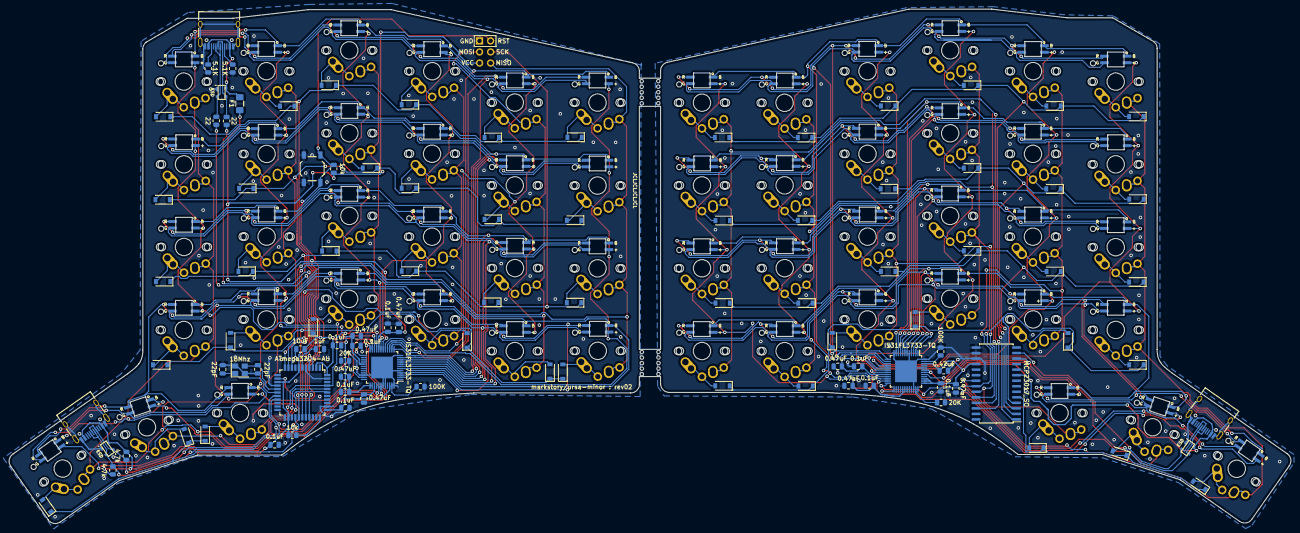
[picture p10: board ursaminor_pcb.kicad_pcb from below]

Board: 2 copper layers, 294.3 x 118.1 mm, 209 parts (155 on the bottom side), 142 nets.

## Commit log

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2021-07-18 Add right side components to schematics
    Still need to get a USBC port for the upstream connection.
    Not jazzed about using TRRS for the interconnects, but I need to figure
    out how USBC ports would work there. TRRS might be simpler given that
    this will be a PCB board.
    [tryptris_pcb.sch]
2021-07-18 Revise schematic
    * Use a better USB connector schematic and footprint for a through-hole
    connector.
    [tryptris_pcb.sch]
2021-07-18 Started left side of PCB
    * Got switches and diodes for the left side placed.
    [tryptris_pcb.sch]
2021-07-22 PCB components roughly placed
    * Removed duplicate resistors on D- and D+
    * Roughly placed all components. MCU and IO expander and resistors are
    all on the back to save board space. I'm hoping that the board can fit
    inside the existing switch place outline.
    [tryptris_pcb.kicad_pcb, tryptris_pcb.sch]
2021-07-25 Made progress on the left side routing.
    I am going to put the components on the bottom (except diodes), and
    ports on the top so that the board can be lower to the table.
    A bunch of routing for the left side is done after a few different
    attempts.
    [tryptris_pcb-Edge_Cuts-left.dxf, tryptris_pcb-Edge_Cuts-right.dxf, tryptris_pcb.kicad_pcb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]
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2021-07-26 Move components to a block outside the switch matrix
    * Having the ports top mounted will let the board be lower profile.
    * Having the components on top looks kind of cool too.
    * Roughly routed the entire left sideci!
    [tryptris-pcb-edge-cut-left-component-block.dxf, tryptris_pcb.kicad_pcb, tryptris_pcb.sch]
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2021-07-28 Fix missing connections and ground fill around crystal
    [tryptris_pcb.kicad_pcb]
2021-07-29 Fix ERC and DRC errors.
    Move right half to use VSS instead of GND and add power flags to remove
    net links between sides.
    [tryptris_pcb.kicad_pcb, tryptris_pcb.sch]
2021-07-29 Improve routing around crystal
    * I had scl and sda running under the crystal.
    * Fix 5v not going through decoupling capacitors.
    [tryptris_pcb.kicad_pcb]
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2021-08-01 Add center 'card' and mousebites.
    These help keep the board together. I'm thinking the card could
    either make several keychain items, or a small piece of art.
    [tryptris_pcb.kicad_pcb]
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2021-08-02 Fix TRRS wiring and improve grounding
    * Don't route gnd for trrs through the crystal. Instead send it around the
    crystal and into the larger ground plane of the MCU.
    * Fix the right side wiring. 5V should pass through the resisitors
    before being connected to the signal wires. The goal is to provide
    background voltage not flood the signal.
    [tryptris_pcb.kicad_pcb, tryptris_pcb.sch]
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2021-08-04 Tweak routing, different back image and new submodules
    Try out some other back silkscreen images
    [tryptris_pcb.kicad_pcb]
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2021-08-15 Revise center block more
    * Make solar model larger.
    * Shrink size of block so it fits on a keychain better.
    * Align items better.
    * Normalize width of edge cut lines.
    [tryptris_pcb.kicad_pcb]
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2021-08-16 Add constellation back silkscreens
    Considering renaming this project to one of the constellations so that
    everything fits thematically and putting the chosen constellation on the
    center block.
    [tryptris_pcb.kicad_pcb]
2021-08-22 Swap TRRS connectors out for USBC
    I have never been a big fan of TRRS and using USBC should be ok as I'm
    keeping the 5V and GND pins the same as with USB.
    [tryptris_pcb.kicad_pcb, tryptris_pcb.sch]
2021-08-22 Add 3D models
    I had to hack up the gitmodules locally to point at the 3dmodels, I'll
    need to find a better way to do that.
    [MX-Alps-Choc-1U-NoLED.step, USB4085-GF-A.step]
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2021-08-25 Put diodes on the bottom
    This lets the board top be much cleaner and there is no risk of the
    diodes impacting switches.
    [tryptris_pcb.kicad_pcb]
2021-08-27 Start schematics for RGB matrix.
    No idea if this is remotely correct. I will need to check my design
    against another design that uses the same RGB driver.
    [rgb matrix.sch, tryptris_pcb.kicad_pcb, tryptris_pcb.sch]
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2021-08-28 Fix ERC errors.
    [rgb matrix.sch]
2021-08-28 Fix power sources.
    [rgb matrix.sch]
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2021-09-04 Move RGB design to a new directory
    I want to have the RGB and non RGB designs in the same branch.
    [bill-of-materials.csv, rgb matrix.sch, tryptris_pcb.kicad_pcb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]
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2021-09-04 Add RGB specific silk screens
    Don't want to silkscreen over the RGB holes. Also remove some cruft.
    [tryptris_pcb.kicad_pcb]
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2021-09-06 Move interconnect ports
    I got some feedback that they might be tight for some cables. By sliding
    the ports down a bit they can stay at the same angle and also give more
    space for cable housing.
    [tryptris_pcb.kicad_pcb]
2021-09-06 Move RGB LED footprint to a local lib
    I don't want as much content on the silkscreen.
    [rgb matrix.sch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]
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2021-09-08 Make schematic clearer
    * Improve routing around mounting holes
    * Fix all DRC errors.
    [rgb matrix.sch, tryptris_pcb.kicad_pcb]
2021-09-14 Update bill of materials with vendors and part numbers.
    Tweak more routing as well.
    [bill-of-materials.csv, tryptris_pcb.kicad_pcb]
2021-09-19 Update base model to use parts from lcsc
    The footprints for USB ports had to change as I can't get the previous
    footprint shape from lcsc.
    [tryptris_pcb.kicad_pcb, tryptris_pcb.sch]
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2021-09-23 Move I2C resistors to the left side for bling
    This should ensure that the LED drivers on the left side work correctly
    when the right side is not plugged in.
    [tryptris_pcb.kicad_pcb, tryptris_pcb.sch]
2021-09-23 Move I2C resistors to MCU side
    This lets the right side be simpler and visually cleaner. It also
    matches the component layout of the bling version.
    [tryptris_pcb.kicad_pcb, tryptris_pcb.sch]
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2021-09-28 Fix ISP wiring
    I got the pins wrong.
    [tryptris_pcb.kicad_pcb, tryptris_pcb.sch]
2021-09-28 Fix ISP connection and move mounting holes
    I had the pins wrong. Top mounting holes are more equal in height and
    evenly spread around the board.
    [tryptris_pcb.kicad_pcb, tryptris_pcb.sch]
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2021-10-02 Fix stray trace.
    [tryptris_pcb.kicad_pcb]
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2021-10-26 Fix DRC and add jcl tag
    [tryptris_pcb-B_Cu.gbr, tryptris_pcb-B_Mask.gbr, tryptris_pcb-B_Paste.gbr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]
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2021-10-26 More plotting fixes.
    [ursaminor_pcb.kicad_pcb]
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2021-10-30 Use 5mm mousebites instead
    The reveiwers at JLCPCB requested wider mousebites as 2mm
    ones are 'too small'.
    [ursaminor_pcb.kicad_pcb]
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2022-01-23 Fix LED driver wiring
    - Caps were not in ordered as per the docs. This doesn't matter *too*
    much but it is nice to be more correct.
    - IS31FL3733 needs SDB set high to ensure the chip is always on.
    Previously it was pulled low causing the chip to shut off.
    [rgb matrix.sch, ursaminor_pcb.kicad_pcb]
2022-01-24 Remove stray trace and fix fill zones
    Found some problems in the printed boards.
    [ursaminor_pcb.kicad_pcb]
2022-01-24 Tweak routing to improve fill areas
    Found some gaps on the printed boards that could be filled.
    [ursaminor_pcb.kicad_pcb]
2022-02-25 Fix incorrectly wired ESD
    [ursaminor_pcb.kicad_pcb, ursaminor_pcb.sch]
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2022-02-25 Start working on bling-base
    * Use north face LEDS as south facing ones have a tendency to shine in
    my eyes.
    * Import the board outline from onshape.
    [rgb matrix.sch, ursaminor_pcb.kicad_pcb]
2022-02-27 Get left side components placed
    Routing is going to be tricky but it still seems doable.
    [ursaminor_pcb.kicad_pcb]
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2022-03-09 Get RGB matrix on left side roughly routed
    If I can get the left side to work, the right should be easier.
    [ursaminor_pcb.kicad_pcb]
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2022-03-19 Routing MCU and LED driver
    * Roughly finished on the MCU. I think components are still close to the
    required pins.
    * Starting to routes traces out of LED driver to the matrix lines. I had
    to rotate the driver and this caused a relayout of the surrounding
    area.
    [ursaminor_pcb.kicad_pcb]
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2022-03-27 Clean up right side and roughly place components.
    Still need to figure out the right side LED driver.
    [ursaminor_pcb.kicad_pcb]
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2022-04-10 Remove mounting holes as they didn't end up working
    [ursaminor_pcb.kicad_pcb]
2022-04-11 Fix DRC errors.
    [ursaminor_pcb.kicad_pcb]
2022-04-11 Reduce area used and fix outline and DRC
    [ursaminor_pcb.kicad_pcb]
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
